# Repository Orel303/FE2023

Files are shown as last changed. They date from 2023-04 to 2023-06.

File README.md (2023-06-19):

# О содержании FE2023 гита
1) В папке 3D модели хранятся все модели, которые я использовал для своей машинки. В файле 2 этаж.ipt находится 3д модель 2 этажа на моём роботе, где находятся все электрические схемы и компоненты

2) В папке Видео в данной папке хранится  txt документ Ссылка на видео.txt, в котором находится ссылка на видео на площадке ютуб. В видео есть проезд машинки квалификацию, финал и рассказ о строение робота.

3) В папке Программы хранятся все нужные файлы для запуска машинки. Подробнее в Пояснения к программам
   
4) В папке Ресурсы хранятся фотографии для README.md

5) В папке Технический журнал находятся три документа, в них рассмотрено устройство робота и логика прохождения трассы.
  
6) В папке Фотографии находятся семь фотографий, из них шесть фотографий робота с разных ракурсов и одна фотогрфия команды.

# Пояснения к программам
Здесь находится краткий разбор программ, которые я использую для робота.
1) RobotAPI.py - в этом файле содержится класс для работы робота с камерой. Робот считывант изображение с камеры и работает с ним.
2) autostart.py - этот файл нужен для raspberry pi, чтобы при включении машинки сразу запускалась программа.
3) fe2023_a.ino - этот файл нужен для прошивки ARDUINO.
4) final.py и kvalifikacia.py - эти файлы говорят сами за себя. Строение этих фалов достаточно лёгкое. Основная программа - это kvalifikacia.py. В final.py добавляется распознование и объезд знаков. Вся их работа делится на этапы:
- Ожидание кнопки - программа ждёт кнопку и скорость = 0
- Движение - в kvalifikacia.py робот смотри бортики и линии и по ним едит, а в final.py добавляется распознование знаков и их объезд.
- Остановка - когда робот насчитает 12 пер (это количество линий, которые он проехал оранжевые или синие) он останавливается
5) start_robot.py - в этом файле приложение, при запуске этого файла открывается окошко подключения к raspberry pi(raspberry раздаёт WI-FI сеть) и с помощью этого файла можно загружать файлы final.py или kvalifikacia.py, а также autostart.py

# Загрузка программы на ARDUINO
Здесь я описываю как прошиться плату ARDUINO UNO.
1) Чтобы прошить ARDUINO UNO надо скачать приложение Arduino IDE и установить.
2) После установление приложения надо подключить плату ARDUINO UNO к компьютеру и с помощьюю файла fe2023_a.ino прошить плату. После этих действий переходим к raspberry.

# Загрузка программы на raspberry pi
Здесь я описываю как прошиться raspberry pi.
1) Для того чтобы raspberry работало, надо вытащить карту памяти из raspberry и подключить её к компьютеру. После этого устанавливаем систему и раздаём сеть от raspberry.
2) В папке Программы есть файл start_robot.py и именно он помогает подключиться к raspberry и загрузить прогрумму.
- Ниже приведён скримок экрана start_robot.py и объяснение кнопок
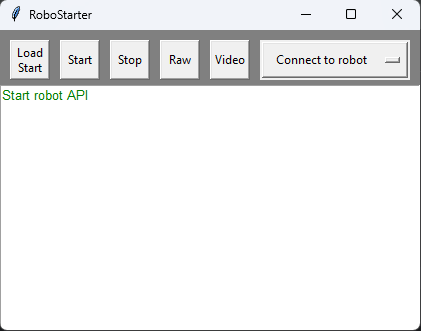
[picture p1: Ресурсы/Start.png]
- 
- В нём мы видим кнопки: LoadStart, Start, Stop, Raw, Video, Connect to robot. Я расскажу про каждую из кнопок и как её использовать.
1. Кнопка LoadStart нужна для быстрой загрузки файла final.py или kvalifikacia.py, а также для загрузки файла autostart.py, которые автоматически запускает указанные файлы.
2. Кнопка Start нужна для уже загруженного файла, чтобы его перезапустить или перезапустить с изменениями.
3. Кнопка Stop останавливает прогрумму и робот перестаёт ехать.
4. Кнопка Raw это настройка формата изображения.
5. Кнопка Video включает видео с камеры машины.
6. Кнопка Connect to robot это подключение к роботу.
3) Инструкция к загрузке файла на raspberry pi:
1. Подключаемся к сети робота, в моём случае "Racer2".
2. Потом нажимаем на кнопку "Connect to robot" и подключаемся с помощью приложения к роботу.
3. После подключения нажимаем кнопку "LoadStart" и загружаем нужную нам прогрумму.
4. Нажимаем на кнопку "Video", в отдельном окне появляется видео с робота.
5. Нажимаем кнопку на роботе и всё готово, робот должен поехать.

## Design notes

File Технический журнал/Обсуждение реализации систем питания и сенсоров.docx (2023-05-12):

Система питания в моей машине состоит из батарейного отсека и проводов, которые подключены к плате:

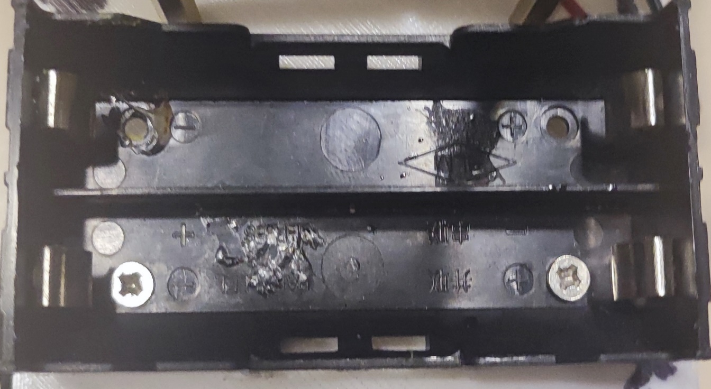
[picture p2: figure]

Плата была смоделирована в easyEDA и на ней находятся многие основные компоненты, а именно:

- кнопка

- ключ

- RGB светодиод

- подключения питания

- подключения сервомотора

- подключения вольтметра

- стабилизатор напряжения

- плата ARDUINO UNO (снизу смоделированной платы)

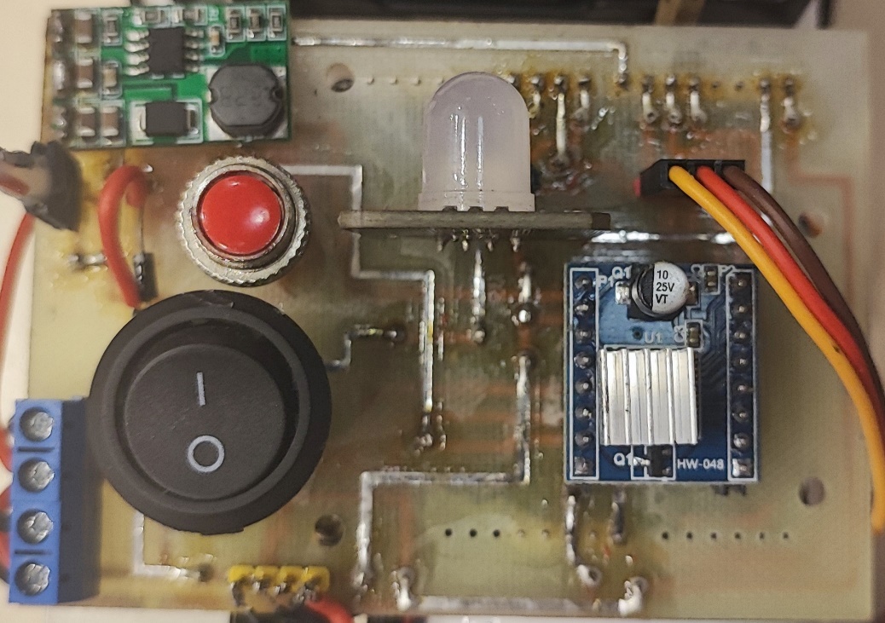
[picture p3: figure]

Схема платы из EasyEDA:

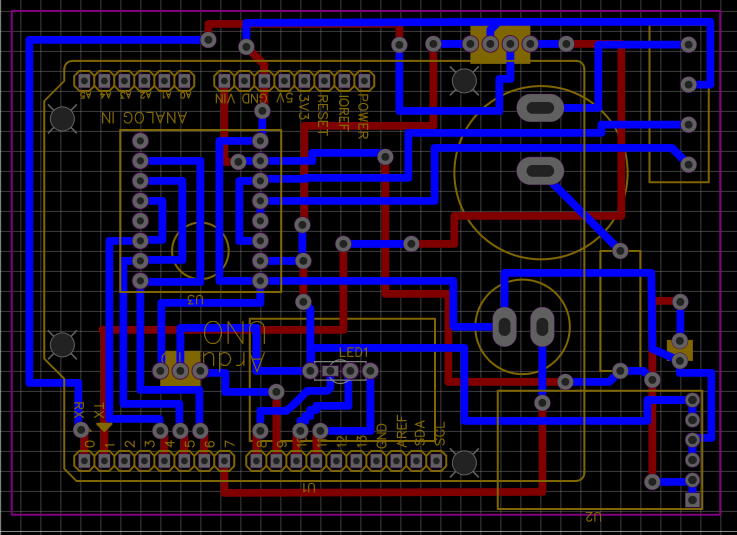
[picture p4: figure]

Синий цвет — это контакты снизу платы.

Красный цвет — это контакты сверху платы.

Плата ARDUINO UNO:

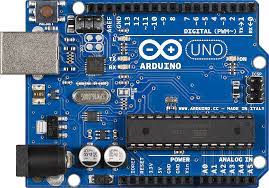
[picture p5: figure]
Arduino Uno R3. Описание, характеристики, распиновка, подключение

Но платы arduino недостаточно ведь в моей машинке она является исполняющей платой, а смоделированная плата соединяет все компоненты. Поэтому я решил поставить py raspberry и именно в неё записывается основной код и идёт картинка с камеры. В raspberry записывается код (алгоритм), который отдаёт команды плате arduino и машинке движется.

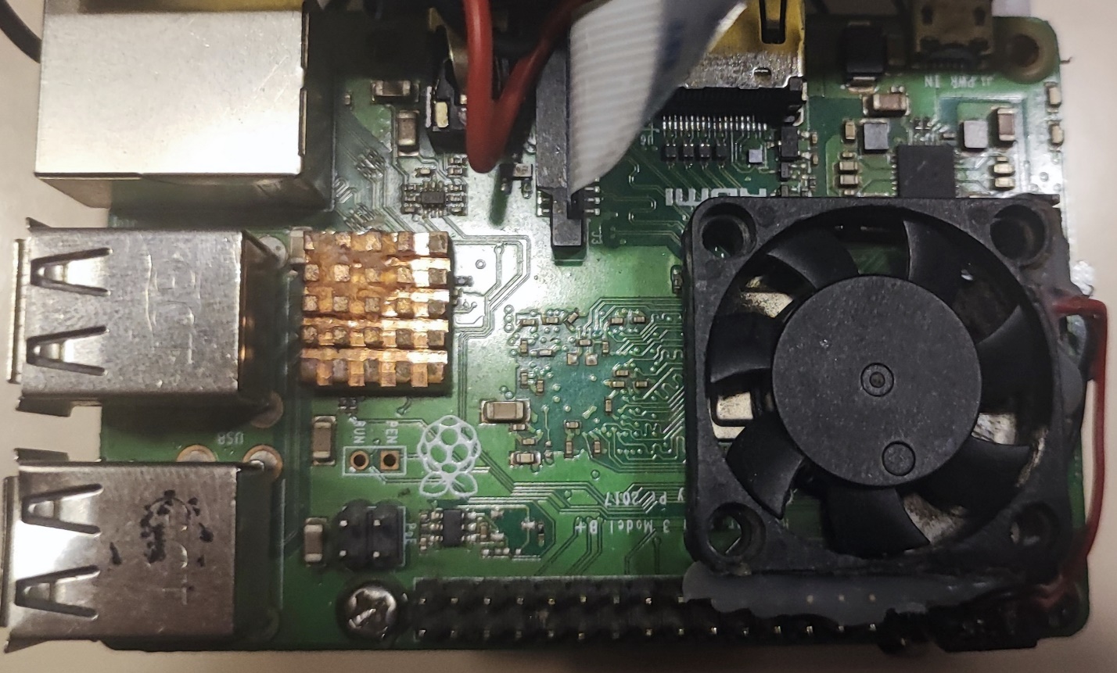
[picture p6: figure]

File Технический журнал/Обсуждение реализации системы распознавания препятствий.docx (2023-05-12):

В моём коде присутствует система распознавания препятствий с помощью камеры. Всё распознавание происходит с помощью данных библиотек:

import cv2

import RobotAPI as rapi

import numpy as np

import serial

import time.

Я сделал для камеры распознавание по окошкам, в данных окошках камера ищет HSV и когда его видит срабатывают определённая функция, которая прописана в коде. В пример можно провести часть кода из квалификации, когда камера замечает линию и что она при этом делает:

if direction == 'orange':

u = -90 // поворот сервы

if direction == 'blue':

u = 90 // поворот сервы

По такому же принципу работает распознавания зелёных или красных знаков, только с усложнением в виде определённой формулы:

kp = 0.4

kd = 0.4

if znak1 == "red":

e = (220 - (yz+hz)*1.1) - (xz+wz)

else:

e = (140 + (yz+hz)*1.1) - (xz)

if e > -2 and e < 2: e = 0

u = e * kp + (e - e_oldz) * kd

e_oldz = e

if u > 90: u = 90

if u < -90: u = -90

Также в коде присутствует система приоритетов. Например, если камера видит два объекта, то она использует функцию только для ближнего объекта.

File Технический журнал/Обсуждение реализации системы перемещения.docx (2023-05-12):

В моём транспортном средстве работает задний привод. Я его выбрал, потому что он был самым лучшим вариантом, а именно лучший угол поворота колёс. У заднего и переднего привода меньше угол поворота колёс, что мне не подходит.

На выбор у меня было 3 сервопривода.

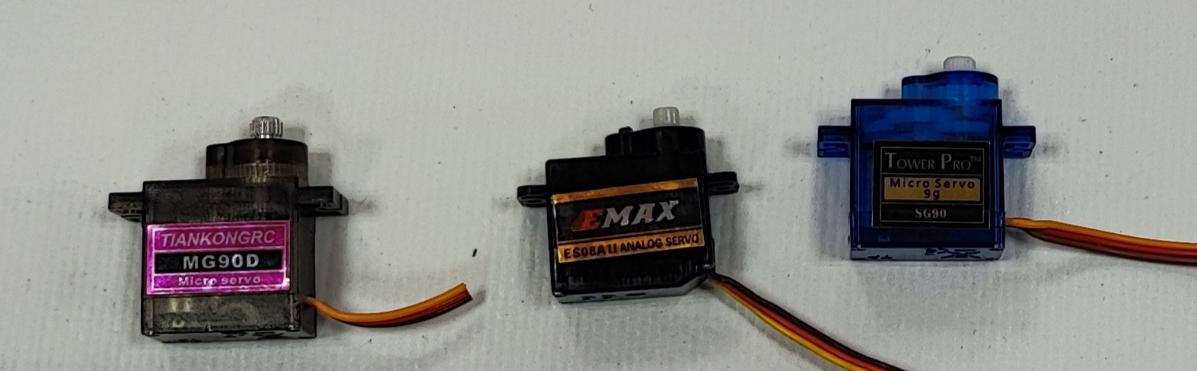
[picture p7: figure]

По характеристикам они примерно одинаковые, но я выбрал с железным редуктором т.к. он более надёжный.

Двигатели у меня было тоже в 3-х вариантов и я выбрал тот, который посередине. По бокам двигатели мощнее, слева на 500 оборотов, а справа на 1000 оборотов. Мой двигатель хоть и не мощный, но на 1000 оборотов и лёгкий. Он идеально подошёл в мою ходовую часть и из-за этого я его выбрал.

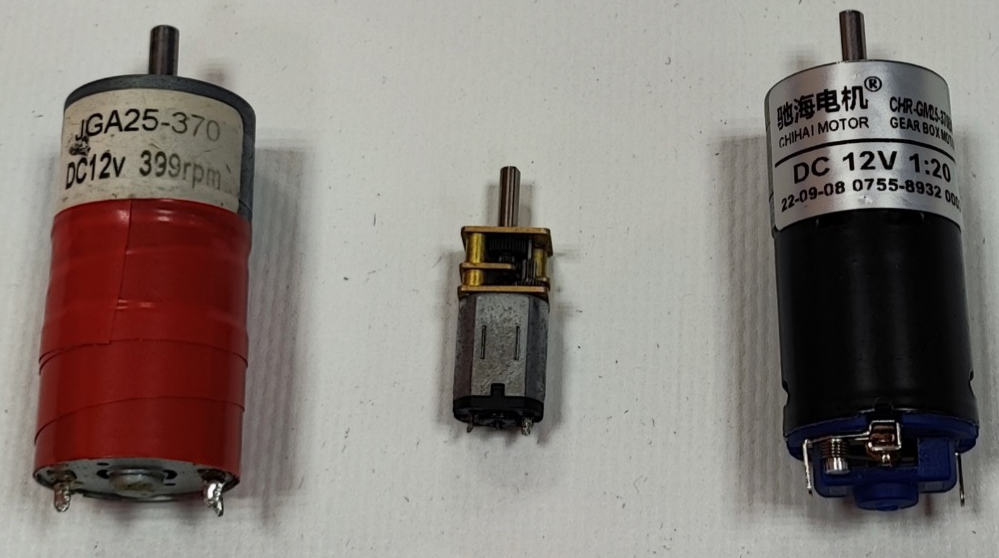
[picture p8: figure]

Также мне было дано на выбор 3 колеса, левое очень большое и это мне не подходит. Справа было средненькое колесо, но оно с мягкой резиной и широкое и тоже мне не подходит. Посередине было нужное мне колесо. Оно с жёсткой резиной и узкое.

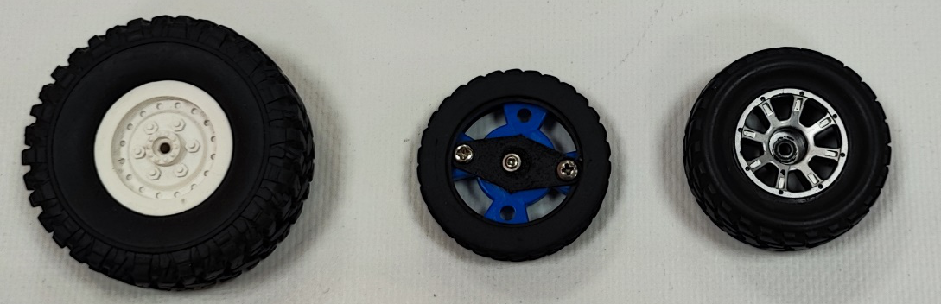
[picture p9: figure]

Раму и подвеску я взял с машинки и всё это установил со всеми подобранными компонентами.

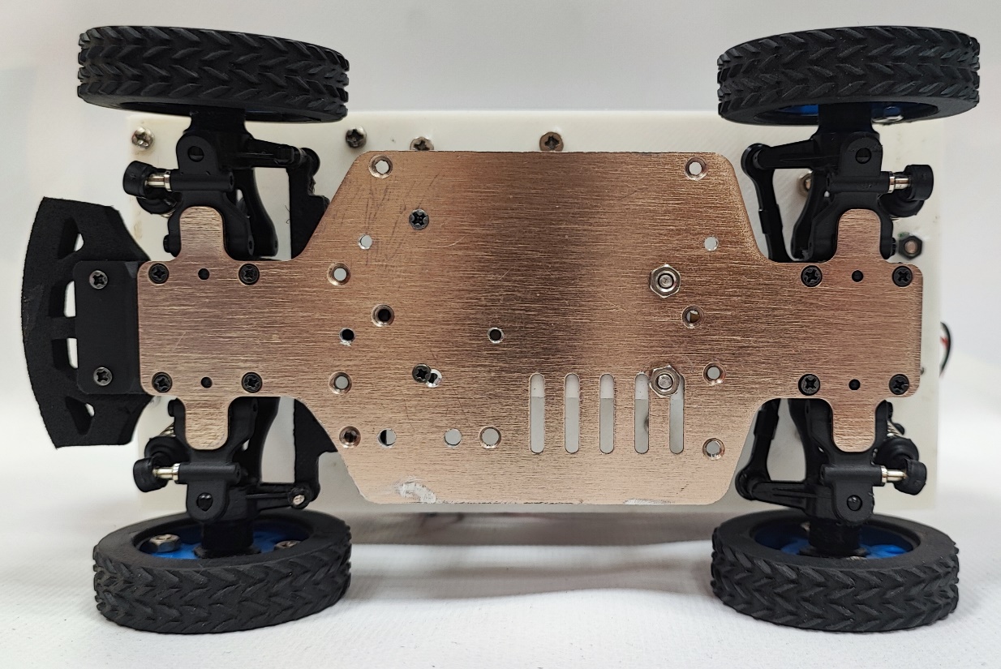
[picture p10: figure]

Для сервопривода я смоделировал и поставил рулевую рейку, т.к. рейка, которая стояла на машинке, мне не подходила. Также я смоделировал крепления для мотора и сервопривода чтоб на соревнованиях они у меня не улетели.

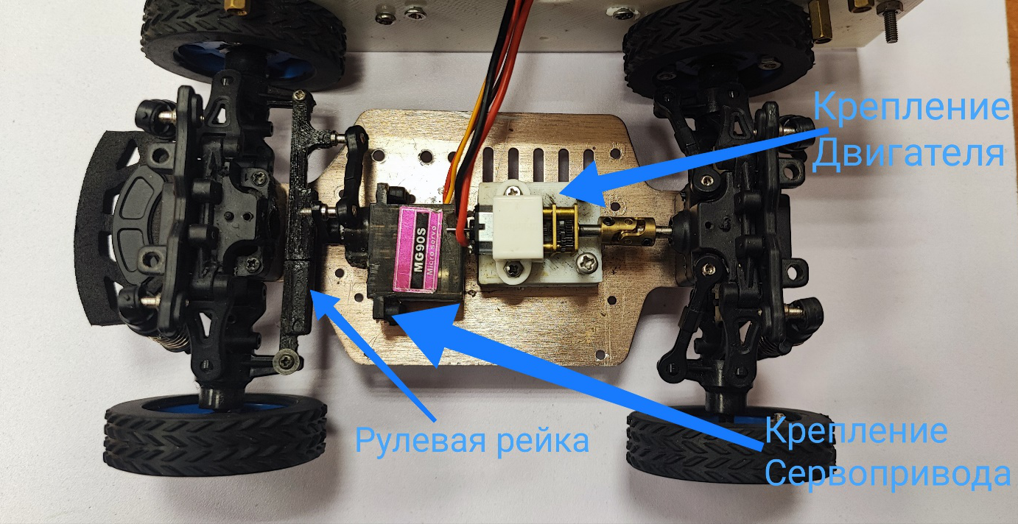
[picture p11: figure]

Схема:

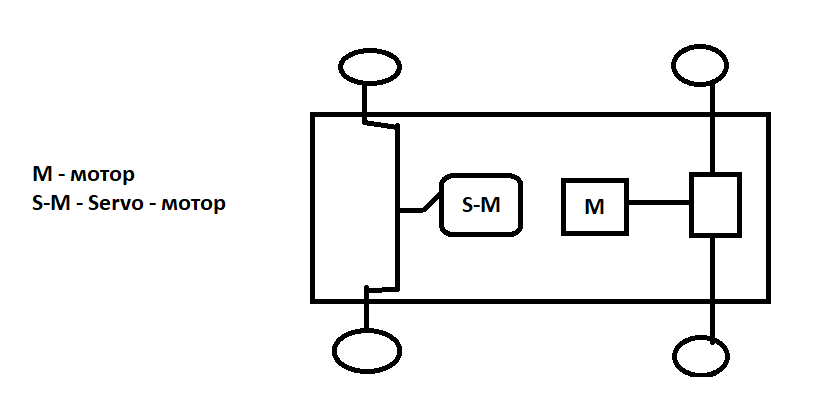
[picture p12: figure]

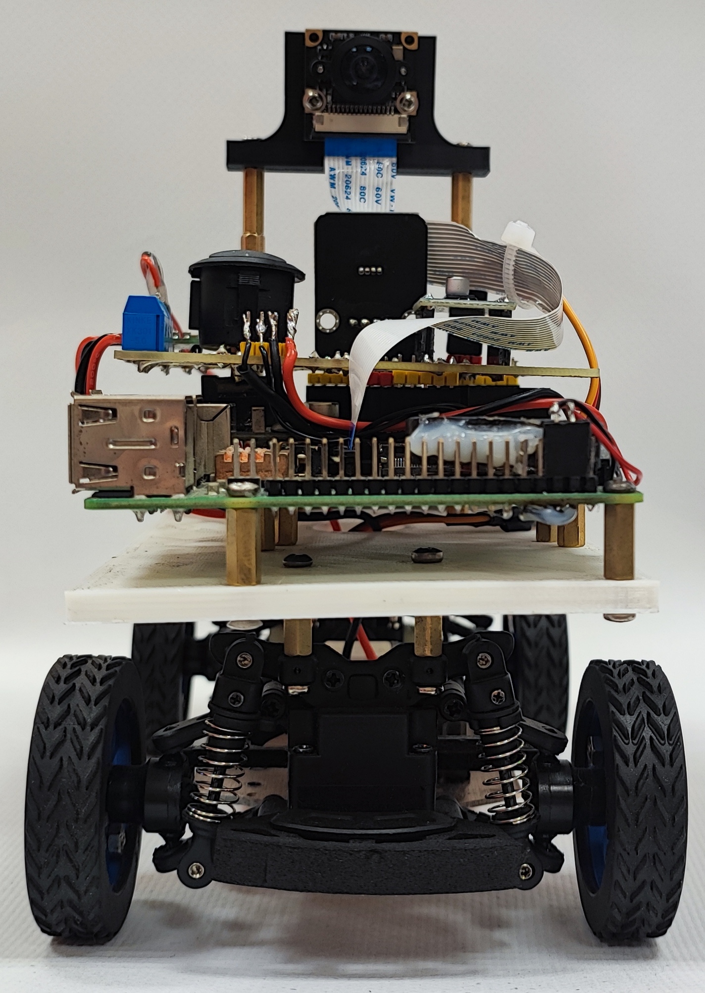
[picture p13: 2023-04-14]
Фотографии/Вид спереди.jpg

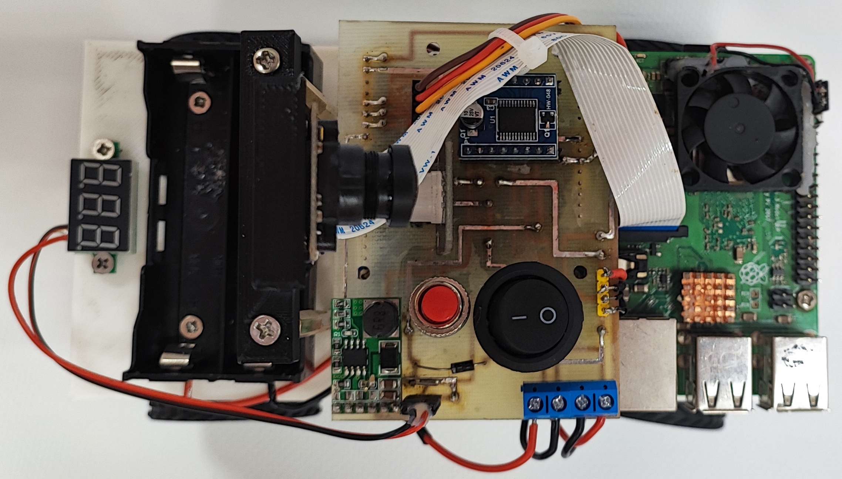
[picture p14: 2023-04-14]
Фотографии/Вид сверху.jpg

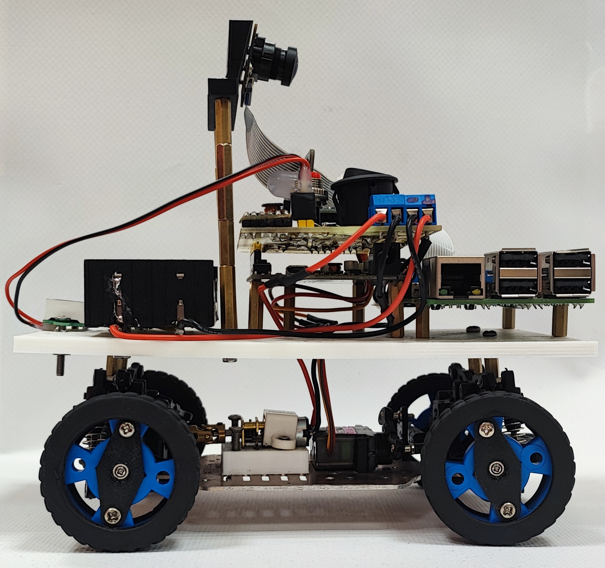
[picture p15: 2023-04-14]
Фотографии/Вид справа.jpg

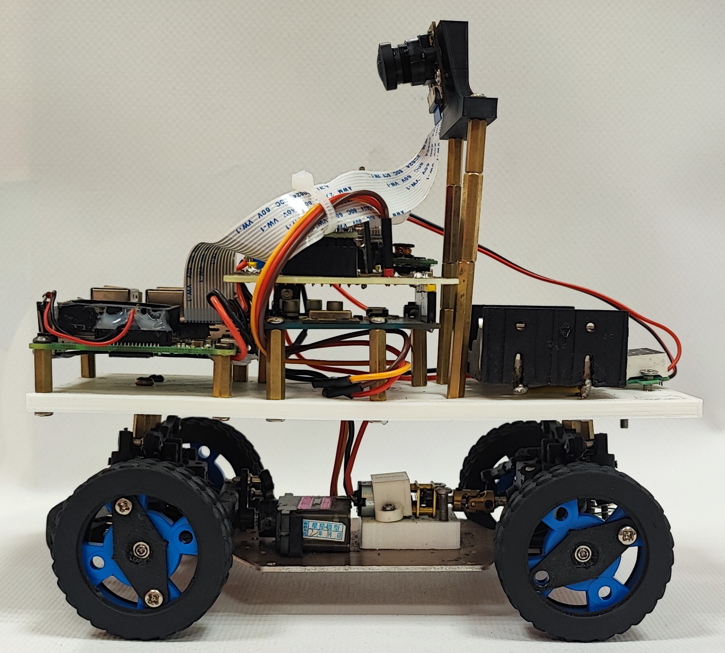
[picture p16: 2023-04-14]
Фотографии/Вид слева.jpg

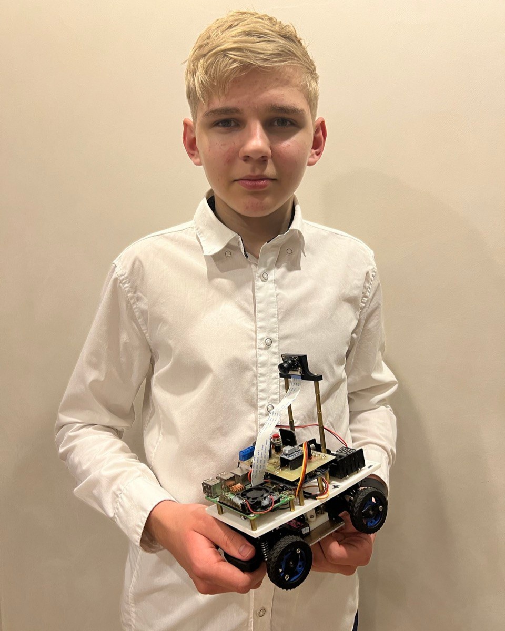
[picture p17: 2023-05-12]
Фотографии/Фото команды.jpg

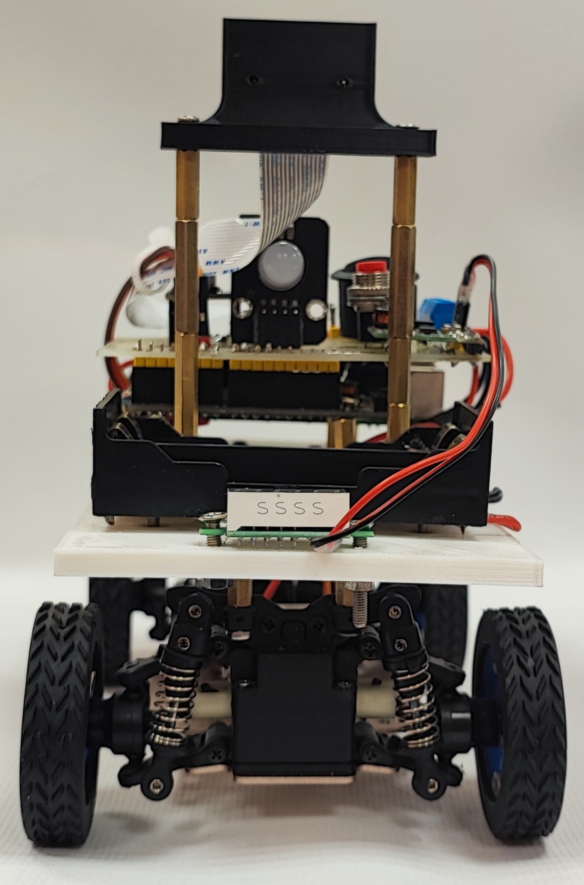
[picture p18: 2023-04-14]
Фотографии/Вид сзади.jpg

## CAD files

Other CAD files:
3D модели/2 этаж.ipt

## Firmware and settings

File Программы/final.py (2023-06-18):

import cv2              # Импорт библиотек
import RobotAPI as rapi
import numpy as np
import serial
import time

port = serial.Serial("/dev/ttyS0", baudrate=115200, stopbits=serial.STOPBITS_ONE)   # Создание переменных
robot = rapi.RobotAPI(flag_serial=False)
robot.set_camera(100, 640, 480)

message = ""
fps = 0
fps1 = 0
fps_time = 0
flagpon = False

timesp = [0, 0, 0, 0]
indextime = 0
a = 0
b = 0
indexminitime = 0


znaksp = [[0, 0, 0], [0, 0, 0], [0, 0, 0], [0, 0, 0]]
znaktime = [[0, 0, 0], [0, 0, 0], [0, 0, 0], [0, 0, 0]]
red = 5
green = 3
indesp = 0
flagkub = False

xb11, yb11 = 0, 260
xb21, yb21 = 240, 300


xb12, yb12 = 400, 260
xb22, yb22 = 640, 300


xz1, yz1 = 80, 220
xz2, yz2 = 560, 390

xp1, yp1 = 300, 400
xp2, yp2 = 340, 430

lowb=np.array([0,0,0])
upb=np.array([180,255,45])


lowbl=np.array([90,100,50])
upbl=np.array([120,255,255])


lowor=np.array([0,100,50])
upor=np.array([30,255,255])

lowred=np.array([0,100,50])
upred=np.array([6,255,255])

lowred1=np.array([170,100,50])
upred1=np.array([180,255,255])


lowgreen=np.array([72,200,38])
upgreen=np.array([83,255,166])

e_old = 0
e_oldz = 0
dat1 = 0
dat2 = 0
dat1_old = 0
dat2_old = 0
timerd1 = time.time()
timerd2 = time.time()
timerznak = time.time()

timer_dat1 = time.time()
timer_stop1 = time.time()


deg = 0
speed = 0
color = 6
inn = ""
line = 'none'
direction = 'none'

znak1 = 'none'
znak2 = 'none'
per = 0
time_per = time.time()
time_z = time.time()
timer_b = time.time()
timer_stop = time.time()
timer_dat = time.time()
xz, yz, wz, hz =0,0,0,0
flagper = False
flagpov = False
flag1 = False
timer1 = 3.5
state = 0
tt = 0
def black_line():       # Функция распознования линии
    global xb11, yb11, xb21, yb21, xb12, yb12, xb22, yb22, lowb, upb, dat1, dat2,timerd1,timerd2,dat1_old,dat2_old
    datb1 = frame[yb11:yb21, xb11:xb21]
    hsv1 = cv2.cvtColor(datb1, cv2.COLOR_BGR2HSV)
    maskd1 = cv2.inRange(hsv1, lowb, upb)
    gray = cv2.cvtColor(maskd1, cv2.COLOR_GRAY2BGR)
    frame[yb11:yb21, xb11:xb21] = gray

    imd1, contoursd1, hod1 = cv2.findContours(maskd1, cv2.RETR_TREE, cv2.CHAIN_APPROX_NONE)
    dat1 = 0
    x1, y1, w1, h1 = 0,0,0,0
    for contorb1 in contoursd1:
        x, y, w, h = cv2.boundingRect(contorb1)
        a1 = cv2.contourArea(contorb1)
        if a1 > 150 and x1 + w1 < x + w and a1/w*h>0.5:
            x1, y1, w1, h1 = x, y, w, h
    cv2.rectangle(datb1, (x1, y1), (x1 + w1, y1 + h1), (0, 255, 0), 2)
    dat1 = int(100*(x1 + w1)/(xb21-xb11))
    if dat1 > 0:
        dat1_old = dat1
        timerd1 = time.time()
    else:
        if timerd1 + 0.05 > time.time():
            dat1 = dat1_old






    datb2 = frame[yb12:yb22, xb12:xb22]
    hsv2 = cv2.cvtColor(datb2, cv2.COLOR_BGR2HSV)
    maskd2 = cv2.inRange(hsv2, lowb, upb)
    gray = cv2.cvtColor(maskd2, cv2.COLOR_GRAY2BGR)
    frame[yb12:yb22, xb12:xb22] = gray

    imd2, contoursd2, hod2 = cv2.findContours(maskd2, cv2.RETR_TREE, cv2.CHAIN_APPROX_NONE)
    dat2 = 0
    x2, y2, w2, h2 = xb22 - xb12, 0, 0, 0
    for contorb2 in contoursd2:
        x, y, w, h = cv2.boundingRect(contorb2)
        a1 = cv2.contourArea(contorb2)
        if a1 > 150 and (xb22 - xb12) - x2 < (xb22 - xb12) - x and a1/w*h>0.5:
            x2, y2, w2, h2 = x, y, w, h
    cv2.rectangle(datb2, (x2, y2), (x2 + w2, y2 + h2), (0, 255, 0), 2)
    dat2 = int(100 * ((xb22 - xb12) - x2) / (xb22 - xb12))
    if dat2 > 0:
        dat2_old = dat2
        timerd2 = time.time()
    else:
        if timerd2 + 0.05 > time.time():
            dat2 = dat2_old


def povorot():      # Распознавание линии
    global xp1, yp1, xp2, yp2, line, direction, per, time_per, color, xb21, xb12, timesp, indesp, timerznak
    dat = frame[yp1:yp2, xp1:xp2]
    cv2.rectangle(frame, (xp1, yp1), (xp2, yp2), (0, 255, 0), 2)
    hsv = cv2.cvtColor(dat, cv2.COLOR_BGR2HSV)
    line = 'none'

    if direction == 'none':     # Если нету линии
        mask = cv2.inRange(hsv, lowbl, upbl)
        imd, contours, hod = cv2.findContours(mask, cv2.RETR_TREE, cv2.CHAIN_APPROX_NONE)
        x1, y1, w1, h1 = 0, 0, 0, 0
        for contor in contours:
            x, y, w, h = cv2.boundingRect(contor)
            a1 = cv2.contourArea(contor)
            if a1 > 50 and w1 * h1 < w * h:
                x1, y1, w1, h1 = x, y, w, h
                line = 'blue'
        cv2.rectangle(dat, (x1, y1), (x1 + w1, y1 + h1), (255, 0, 0), 2)

        mask = cv2.inRange(hsv, lowor, upor)
        imd, contours, hod = cv2.findContours(mask, cv2.RETR_TREE, cv2.CHAIN_APPROX_NONE)
        x2, y2, w2, h2 = 0, 0, 0, 0
        for contor in contours:
            x, y, w, h = cv2.boundingRect(contor)
            a1 = cv2.contourArea(contor)
            if a1 > 50 and w2 * h2 < w * h:
                x2, y2, w2, h2 = x, y, w, h
                line = 'orange'
        cv2.rectangle(dat, (x2, y2), (x2 + w2, y2 + h2), (255, 255, 0), 2)
        direction = line
        per = 1
        indesp = 0
        time_per = time.time()
        timerznak = time.time()
    else:
        if direction == 'blue':     # Если линия синия
            # xb21 = 240
            # xb12 = 500
            mask = cv2.inRange(hsv, lowbl, upbl)
            imd, contours, hod = cv2.findContours(mask, cv2.RETR_TREE, cv2.CHAIN_APPROX_NONE)
            x1, y1, w1, h1 = 0, 0, 0, 0
            for contor in contours:
                x, y, w, h = cv2.boundingRect(contor)
                a1 = cv2.contourArea(contor)
                if a1 > 50 and w1 * h1 < w * h:
                    x1, y1, w1, h1 = x, y, w, h
                    line = 'blue'
            cv2.rectangle(dat, (x1, y1), (x1 + w1, y1 + h1), (255, 0, 0), 2)
            if line == 'blue' and time_per + 1 < time.time():
                per += 1
                indesp = 0
                if (per < 6):
                    timesp[(per - 1) % 4] = round(time.time() - time_per, 2)
                time_per = time.time()
                timerznak = time.time()
                color = 2

        if direction == 'orange':       # Если линия оранжевая
            # xb12 = 400
            # xb21 = 140
            mask = cv2.inRange(hsv, lowor, upor)
            imd, contours, hod = cv2.findContours(mask, cv2.RETR_TREE, cv2.CHAIN_APPROX_NONE)
            x2, y2, w2, h2 = 0, 0, 0, 0
            for contor in contours:
                x, y, w, h = cv2.boundingRect(contor)
                a1 = cv2.contourArea(contor)
                if a1 > 50 and w2 * h2 < w * h:
                    x2, y2, w2, h2 = x, y, w, h
                    line = 'orange'
            cv2.rectangle(dat, (x2, y2), (x2 + w2, y2 + h2), (255, 255, 0), 2)
            if line == 'orange' and time_per + 1 < time.time():
                per += 1
                indesp = 0
                if (per < 6):
                    timesp[(per - 1) % 4] = round(time.time() - time_per, 2)
                time_per = time.time()
                timerznak = time.time()
                color = 4


def pd():       # Функция самого исполнителя поворота для линии
    global  e_old,dat2,dat1
    kp = 0.4
    kd = 0.4
    u = 0
    if dat2>0 and dat1>0:
        e = dat2 - dat1
        if e>-2 and e<2: e = 0

        u = e * kp + (e - e_old) * kd
        e_old = e
        if u > 90: u = 90
        if u < -90: u = -90
    else:
        if dat2 == 0 and dat1 == 0:
            if direction == 'orange':
                u = -90
            if direction == 'blue':
                u = 90
        else:
            if dat2 == 0:
                u = -50
            if dat1 == 0:
                u = 50

    return u


def znak():     # Функция распознавания знака (красного или зелёного)
    global xz1, yz1, xz2, yz2, znak1, color,  xz, yz, wz, hz, time_z
    dat = frame[yz1:yz2, xz1:xz2]
    cv2.rectangle(frame, (xz1, yz1), (xz2, yz2), (0, 255, 0), 2)
    hsv = cv2.cvtColor(dat, cv2.COLOR_BGR2HSV)
    mask1 = cv2.inRange(hsv, lowred, upred)
    mask2 = cv2.inRange(hsv, lowred1, upred1)
    mask1 = cv2.bitwise_or(mask1,mask2)
    imd, contours, hod = cv2.findContours(mask1, cv2.RETR_TREE, cv2.CHAIN_APPROX_NONE)
    x2, y2, w2, h2 = 0, 0, 0, 0
    for contor in contours:
        x, y, w, h = cv2.boundingRect(contor)
        a1 = cv2.contourArea(contor)
        if a1 > 200 and w2 * h2 < w * h:
            x2, y2, w2, h2 = x, y, w, h
            znak1 = 'red'
            xz, yz, wz, hz = x2, y2, w2, h2
            color = 5

    mask2 = cv2.inRange(hsv, lowgreen, upgreen)
    imd, contours, hod = cv2.findContours(mask2, cv2.RETR_TREE, cv2.CHAIN_APPROX_NONE)
    x3, y3, w3, h3 = 0, 0, 0, 0
    for contor in contours:
        x, y, w, h = cv2.boundingRect(contor)
        a1 = cv2.contourArea(contor)
        if a1 > 200 and w3 * h3 < w * h:
            x3, y3, w3, h3 = x, y, w, h
            znak1 = "green"
            xz, yz, wz, hz  = x3, y3, w3, h3
            color = 3

    if h3 == 0 and h2 == 0:
        if time_z + 0.1 < time.time():
            znak1 = "none"
            xz, yz, wz, hz = 0,0,0,0
    else:
        time_z = time.time()
        if h3>0 and h2>0:
            if y3+h3>y2+h2:
                cv2.rectangle(dat, (x3, y3), (x3 + w3, y3 + h3), (0, 0, 255), 2)
                znak1 = "green"
                xz, yz, wz, hz = x3, y3, w3, h3
                color = 3

            else:
                cv2.rectangle(dat, (x2, y2), (x2 + w2, y2 + h2), (0, 255, 0), 2)
                znak1 = 'red'
                xz, yz, wz, hz = x2, y2, w2, h2
                color = 5
        else:
            if h3 > 0:
                cv2.rectangle(dat, (x3, y3), (x3 + w3, y3 + h3), (0, 0, 255), 2)
            elif h2>0:
                cv2.rectangle(dat, (x2, y2), (x2 + w2, y2 + h2), (0, 255, 0), 2)

def pd_znak():      # Функция обьезда знака
    global  e_oldz, xz, yz, wz, hz ,znak1
    kp = 0.4
    kd = 0.4
    if znak1 == "red":
        e = (260 - (yz+hz)*1.1) - (xz+wz)
    else:
        e = (200 + (yz+hz)*1.1) - (xz)

    if e > -2 and e < 2: e = 0
    u = e * kp + (e - e_oldz) * kd
    e_oldz = e
    if u > 90: u = 90
    if u < -90: u = -90

    return u

def peres():        #функция перестановки переменной znaksp (список знаков)
    global indextime, a, b, znaksp, indexminitime, timesp
    for i in range(4):
        a = round(timesp[indextime] * 0.34, 2)
        b = round(timesp[indextime] * 0.7, 2)
        if (znaksp[indextime][0] > 0 and znaksp[indextime][1] > 0):
            znaksp[indextime][2] = znaksp[indextime][1]
            znaksp[indextime][1] = 0
        elif (znaksp[indextime][0] > 0):
            if(znaktime[indextime][0] > a):
                if (znaktime[indextime][0] <= b):
                    znaksp[indextime][1] = znaksp[indextime][0]
                    znaksp[indextime][0] = 0
                else:
                    znaksp[indextime][2] = znaksp[indextime][0]
                    znaksp[indextime][0] = 0
        indextime = indextime + 1
while 1:
    frame = robot.get_frame(wait_new_frame=1)

    if speed > 0:       # Начало движения
        black_line()
        znak()
        povorot()
        if znak1 == "none":
            if direction == 'orange' and znak2 == "green":
                if timer_dat + 0.4 > time.time():
                    dat2 = 0

            if direction == 'blue' and znak2 == "red":
                if timer_dat + 0.4 > time.time():
                    dat1 = 0

            deg = pd()
        else:
            if(yz + hz > 160 and flagpov == False):
                znak2 = znak1
                if (flagkub == False and per < 5):
                    znaksp[per % 4][indesp] = color
                    znaktime[per % 4][indesp] = round(time.time() - timerznak, 1)
                    flagkub = True
                    indesp = indesp + 1
                timer_dat1 = time.time()
            if(yz + hz < 100 and flagpov == False):
                flagkub = False
                if per > 8 and flagpon == False:
                    flagpon = True
                    peres()

            timer_dat = time.time()
            deg = pd_znak()

    else:
        black_line()
        znak()
        povorot()
        deg = 0


    if per > 7 and flagper == False:        # Проверка знака после второго круга для разворота или продолжения движения
        speed = 0
        deg = 0
        flagpov = True
        if(znak2 == 'red'):
            if state == 0:
                tt = round(time.time() - timer_dat1,2)
                if tt > 0.6:
                    state = 1
                else:
                    state = 11


            if state == 1:
                if direction == 'blue':
                    deg = -90
                    speed = 100
                if direction == 'orange':
                    deg = 90
                    speed = 100
                if timer_stop1 + 3.2 < time.time():
                    state = 2
                    timer_stop1 = time.time()

            elif state == 2:
                if direction == 'blue':
                    speed = -100
                    deg = 90
                if direction == 'orange':
                    deg = -90
                    speed = -100
                if timer_stop1 + 1.5 < time.time():
                    timer_stop1 = time.time()
                    state = 3

            elif state == 3:
                if direction == 'blue':
                    speed = 100
                    deg = 0
                if direction == 'orange':
                    deg = 0
                    speed = 100
                if timer_stop1 + 1.5 < time.time():
                    speed = 200
                    per = 9
                    if direction == 'blue':
                        direction = 'orange'
                    else:
                        direction = 'blue'
                    flagper = True
                    flagpov = False
                    time_per = time.time()

            if state == 11:
                if direction == 'blue':
                    deg = 90
                    speed = 100
                    if timer_stop1 + 1.8 < time.time():
                        state = 22
                        timer_stop1 = time.time()
                if direction == 'orange':
                    deg = 90
                    speed = 100
                    if timer_stop1 + 3.2 < time.time():
                        state = 22
                        timer_stop1 = time.time()


            elif state == 22:
                if direction == 'blue':
                    speed = -100
                    deg = -90
                    if timer_stop1 + 2.1 < time.time():
                        timer_stop1 = time.time()
                        state = 33
                if direction == 'orange':
                    deg = -90
                    speed = -100
                    if timer_stop1 + 1.5 < time.time():
                        timer_stop1 = time.time()
                        state = 33


            elif state == 33:
                if direction == 'blue':
                    speed = -100
                    deg = 0
                if direction == 'orange':
                    deg = 0
                    speed = -100
                if timer_stop1 + 0.5 < time.time():
                    speed = 200
                    per = 9
                    if direction == 'blue':
                        direction = 'orange'
                    else:
                        direction = 'blue'
                    flagper = True
                    flagpov = False
                    time_per = time.time()



        else:
            speed = 200
            flagper = True
            flagpov = False
    else:
        timer_stop1 = time.time()

    if per == 12 and flagper:       # Проверка перекрестков и если их 12 то остановка (3 круга завершены)
        if timer_stop + timesp[0] * 0.6 < time.time():
            speed = 0
    else:
        timer_stop = time.time()

    message = str(int(speed) + 500) + str(int(deg) + 500) + str(int(color)) +'$'
    port.write(message.encode("utf-8"))

    if port.in_waiting > 0:
        inn = ""
        t = time.time()
        while 1:
            a = str(port.read(), "utf-8")
            if a != '$':
                inn += a
            else:
                break
            if t + 0.02 < time.time():
                break
        port.reset_input_buffer()


    if inn == '0' and timer_b + 1 < time.time():        # Проверка нажатие кнопки
        timer_b = time.time()
        if speed == 0:
            speed = 200
        else:
            speed = 0


    cv2.rectangle(frame, (0, 0), (640, 105), (0, 0, 0), -1)             # Вывод показаний на экран
    cv2.rectangle(frame, (xb11, yb11), (xb21, yb21), (0, 0, 255), 2)
    cv2.rectangle(frame, (xb12, yb12), (xb22, yb22), (0, 0, 255), 2)

    robot.text_to_frame(frame, message, 0, 20)
    robot.text_to_frame(frame, direction, 150, 20)
    robot.text_to_frame(frame, line, 300, 20)
    robot.text_to_frame(frame, znak2, 300, 40)
    robot.text_to_frame(frame, tt, 0, 40)
    robot.text_to_frame(frame, str(dat1) + '  ' + str(dat2), 0, 60)

    fps1 += 1
    if time.time() > fps_time + 1:
        fps_time = time.time()
        fps = fps1
        fps1 = 0

    robot.text_to_frame(frame, 'fps = ' + str(fps), 500, 20)
    robot.text_to_frame(frame, 'time = ' + str(timesp), 200, 65)
    robot.text_to_frame(frame, 'kub = ' + str(znaksp), 0, 90)
    robot.text_to_frame(frame, '' + str(znaktime), 0, 105)
    robot.text_to_frame(frame, 'per = ' + str(per), 500, 40)
    robot.set_frame(frame, 40)

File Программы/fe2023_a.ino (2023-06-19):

#include <Servo.h>
Servo myservo;

void rgb(int r, int g, int b) {
  digitalWrite(8, 1 - r);
  digitalWrite(10, 1 - g);
  digitalWrite(11, 1 - b);
}


void rul(int a) {
  myservo.write(a);
}

void move(int s) {
  s = constrain(s, -255, 255);
  if (s > 0) {
    digitalWrite(4, 0);
    digitalWrite(5, 1);
  }
  else if (s < 0) {
    digitalWrite(4, 1);
    digitalWrite(5, 0);
    s = -s;
  }
  else {
    digitalWrite(4, 0);
    digitalWrite(5, 0);
    s = 0;
  }
  analogWrite(6, s);
}

void setup() {
  Serial.begin(115200);
  myservo.attach(9);
  pinMode(7, INPUT_PULLUP);
  pinMode(8, 1);
  pinMode(10, 1);
  pinMode(11, 1);
  rgb(0, 0, 0);

  pinMode(4, 1);
  pinMode(5, 1);
  pinMode(6, 1);
  rul(90);
}
//move(100);

void loop() {
  int b = digitalRead(7);
  if (Serial.available() > 0) {
    String msg = Serial.readStringUntil('$');
    Serial.print(String(b) + "$");
  }
}

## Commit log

2023-05-12 Create Ресурсы
    1
2023-05-12 Create Ресурсы
